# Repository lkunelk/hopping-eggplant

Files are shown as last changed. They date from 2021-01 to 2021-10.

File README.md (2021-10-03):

# pendulum
Prototype Flywheel Pendulum

## Setting up project
1. create directory catkin_ws/src/
2. clone repo into it

## Install Dependancies in package.xml
1. go to catkin_ws/ and run below command
```
rosdep install --from-paths src --ignore-src -r -y
```

## Running Simulation
1. build (need to do it first time after clone, and any time you modify c++ files)
```
cd ~/catkin_ws
catkin build
```
2. source (do it for each new terminal)
```
source build/setup.bash
```
3. launch simulation
```
roslaunch pendulum sim.launch
```

4. publish to motor directly
```
rostopic pub /flywheel_controller/command std_msgs/Float64 "data: 0.0"
```
5. graph data
```
roslaunch pendulum plots.launch
```
manually add topics to graph. You can see available topics with following:
```
rostopic list
```

7. delete and spawn new model
```
roslaunch pendulum respawn.launch
```

8. quit fast
```
./gk
```

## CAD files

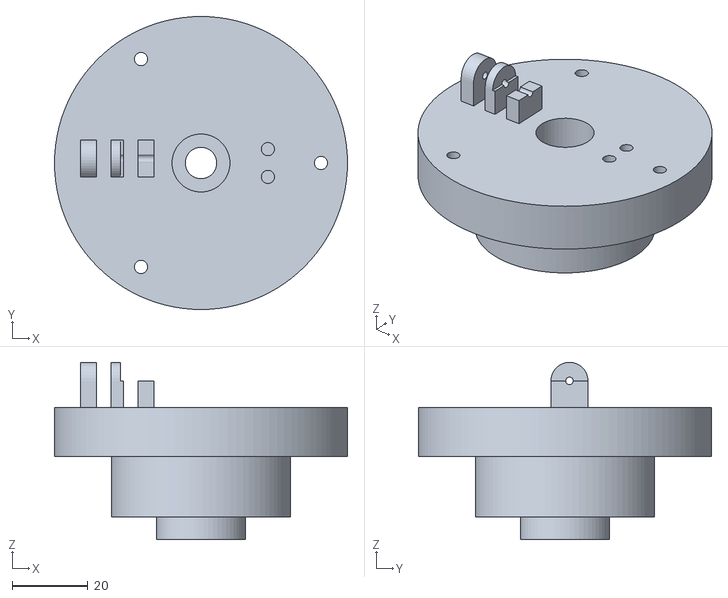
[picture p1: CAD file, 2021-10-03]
full_description/meshes/middle_v13_1.stl
77.3 x 77.3 x 46.8

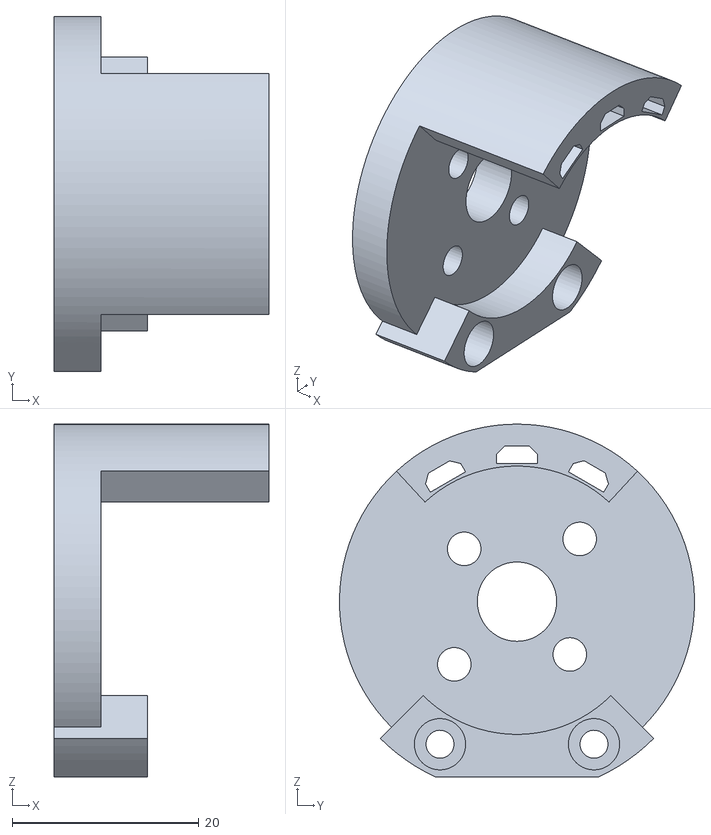
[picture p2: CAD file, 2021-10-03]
full_description/meshes/_bldc_parts.d32996c5-cb5d-48d1-b36d-40a50d399b36_v5_1.stl
23.0 x 38.0 x 37.8

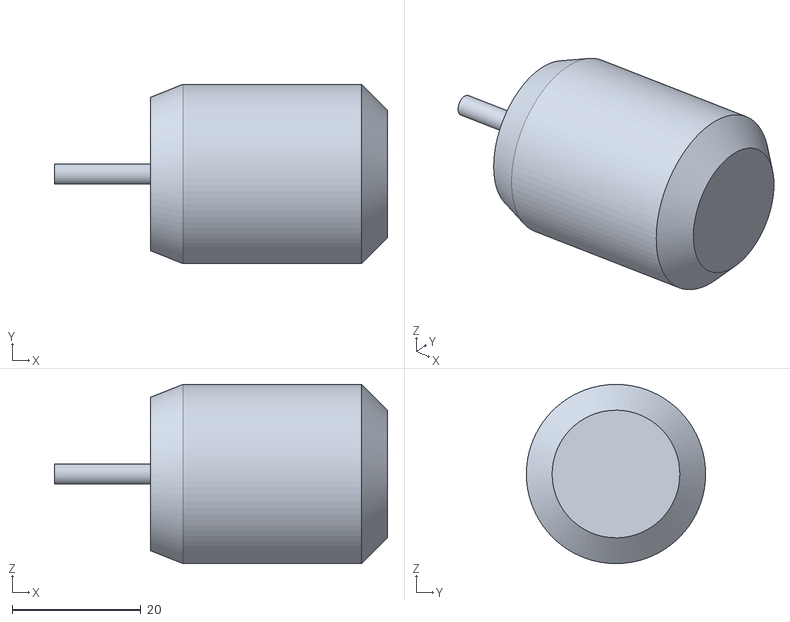
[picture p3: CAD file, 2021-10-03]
full_description/meshes/Turnigy_Aerodrive_SK3_-_2836_v2_1.stl
51.6 x 27.8 x 27.8

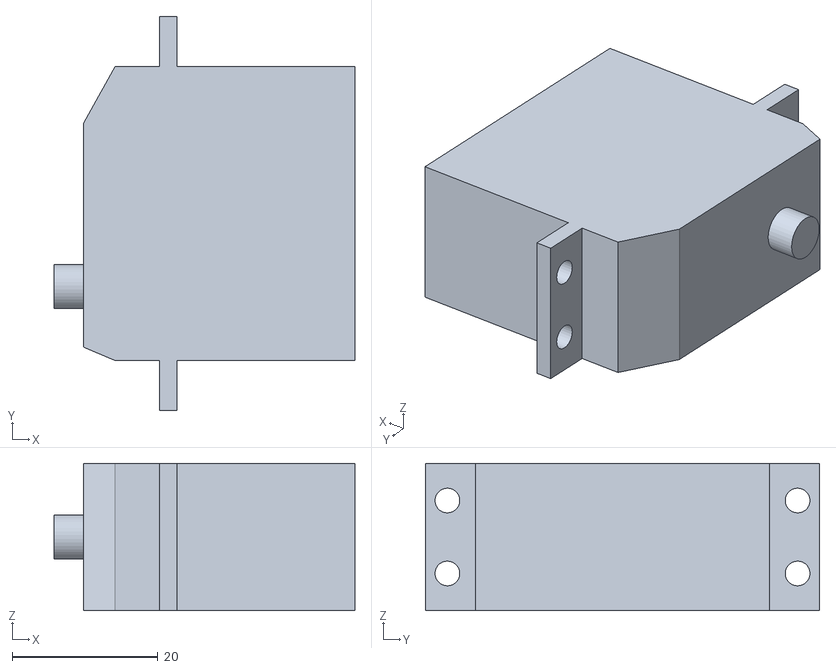
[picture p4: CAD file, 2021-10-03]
full_description/meshes/Savox_SV1270TG_v4_1.stl
41.2 x 54.0 x 20.2

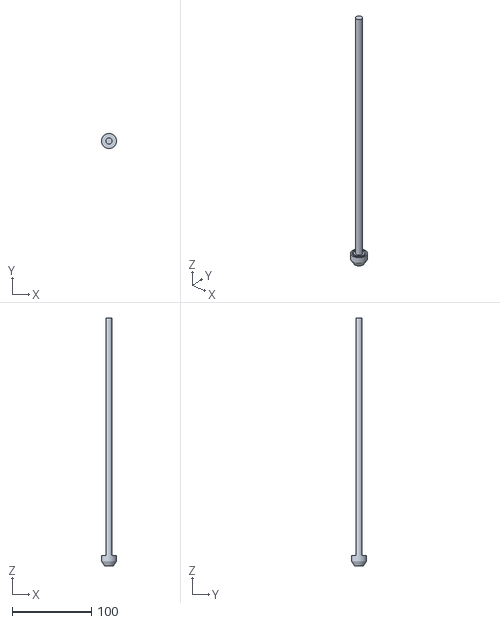
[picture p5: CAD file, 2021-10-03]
full_description/meshes/Leg_0_v2_1.stl
19.0 x 19.0 x 312.8

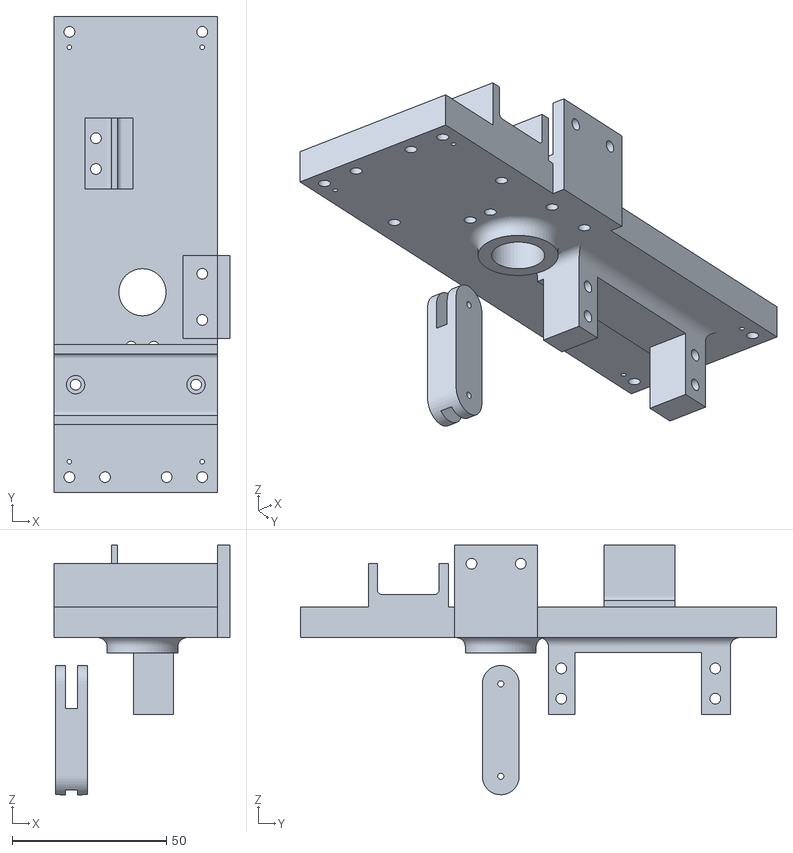
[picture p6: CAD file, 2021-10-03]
full_description/meshes/base_link.stl
57.1 x 154.5 x 81.0

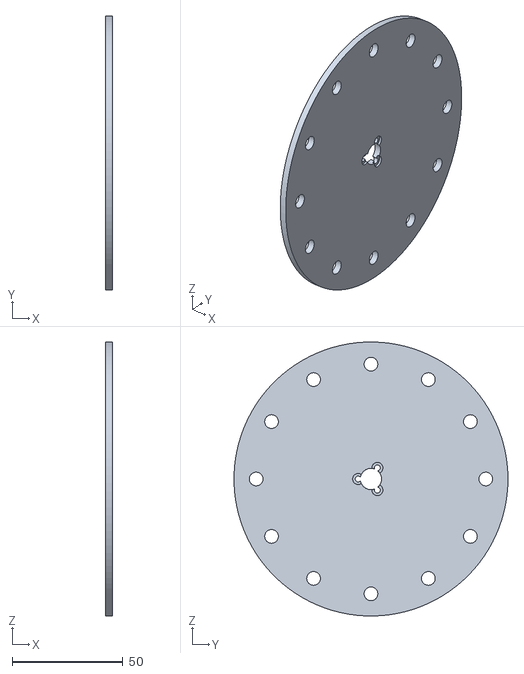
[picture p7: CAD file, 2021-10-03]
full_description/meshes/flywheel_v2_1.stl
3.00 x 123.4 x 123.4

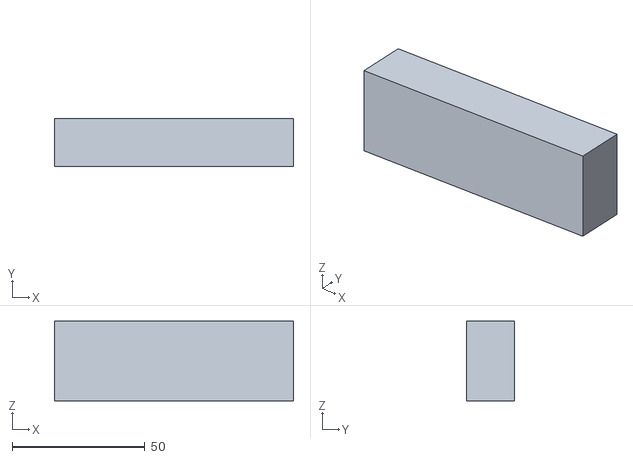
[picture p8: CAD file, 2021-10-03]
full_description/meshes/battery_v2_1.stl
90.0 x 18.0 x 30.0

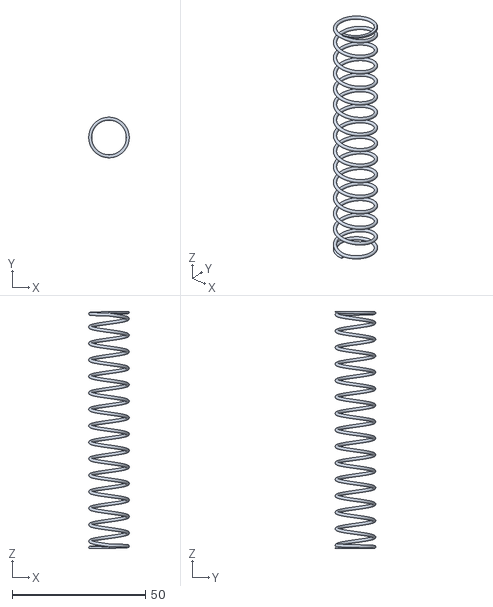
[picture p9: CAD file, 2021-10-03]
full_description/meshes/9657K449_COMPRESSION_SPRING_v1_1.stl
15.2 x 15.2 x 88.9

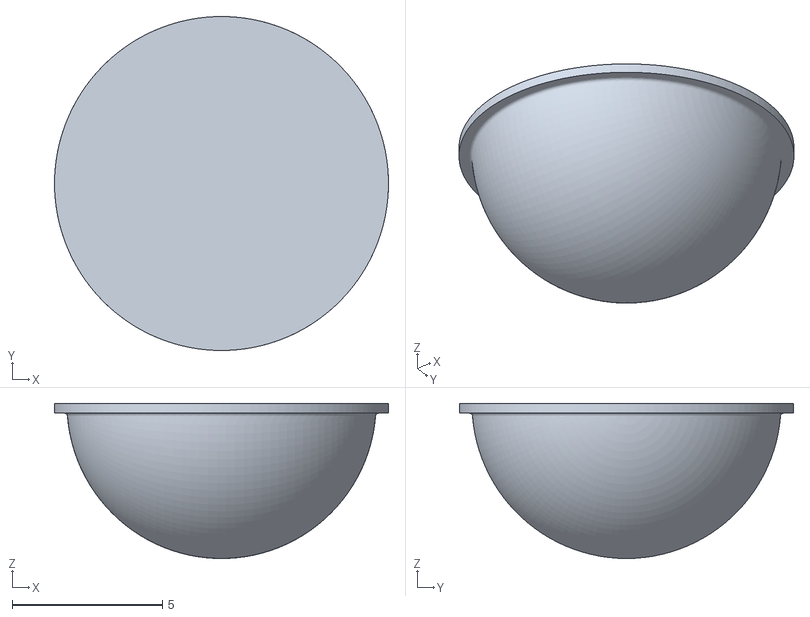
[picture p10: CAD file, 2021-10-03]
full_description/meshes/95495K673_POLYURETHANE_RUBBER_ADHESIVE-BACK_BUMPER_v1_1.stl
11.1 x 11.1 x 5.16

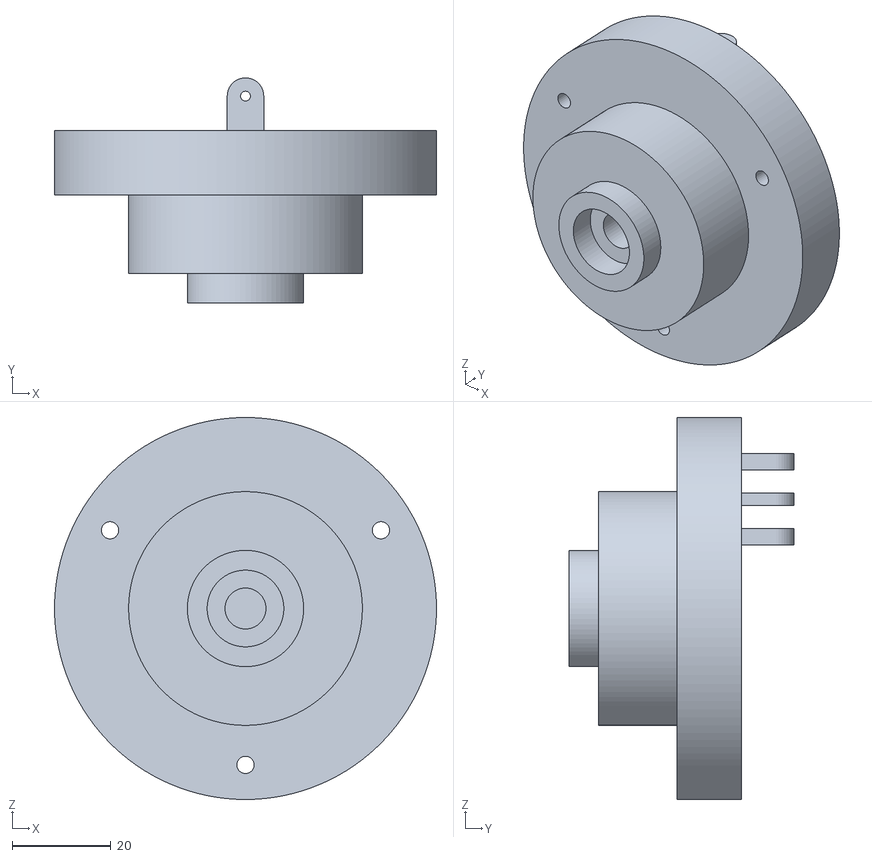
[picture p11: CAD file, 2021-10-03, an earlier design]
full_description/meshes/middle_v7_1.stl
77.3 x 45.6 x 77.3

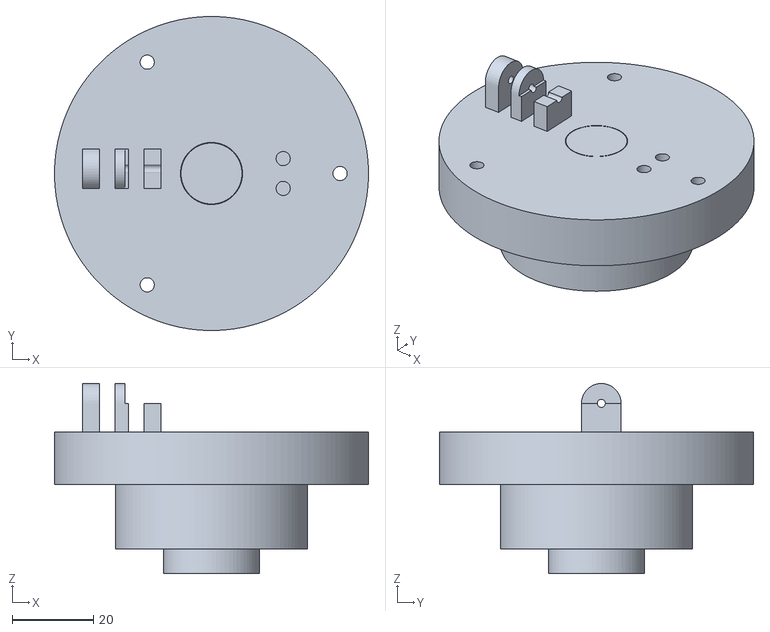
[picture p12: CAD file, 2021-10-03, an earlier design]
full_description/meshes/middle_v8_1.stl
77.3 x 77.3 x 46.8

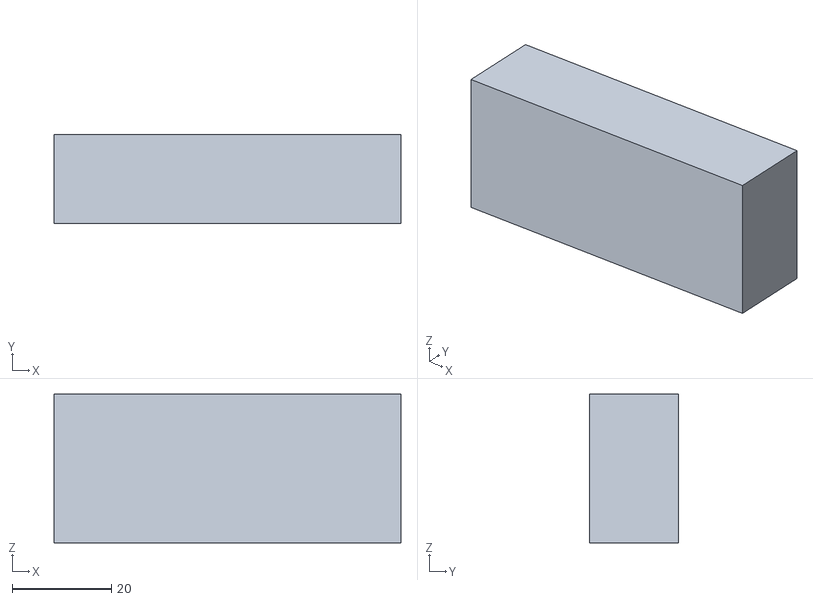
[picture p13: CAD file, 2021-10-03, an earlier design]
full_description/meshes/battery_v1_1.stl
70.0 x 18.0 x 30.0

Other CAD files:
full_description/meshes/middle_v9_1.stl

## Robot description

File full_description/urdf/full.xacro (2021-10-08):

<?xml version="1.0" ?>
<robot name="full" xmlns:xacro="http://www.ros.org/wiki/xacro">

<xacro:include filename="$(find pendulum)/urdf/imu.xacro"/>

<xacro:include filename="$(find full_description)/urdf/materials.xacro" />
<xacro:include filename="$(find full_description)/urdf/full.trans" />
<xacro:include filename="$(find full_description)/urdf/full.gazebo" />
<xacro:property name="COG_X" value="18.6E-3" />
<xacro:property name="COG_Y" value="-0.717E-3" />
<xacro:property name="COG_Z" value="202.078E-3" />

<link name="base_link">
  <inertial>
    <origin rpy="0 0 0" xyz="-0.001293985439476192 0.008696164684669999 0.19102874553521218"/>
    <mass value="0.029100376183393978"/>
    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
  </inertial>
  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
</link>

<link name="yaw_flywheel">
  <inertial>
    <origin rpy="0 0 0" xyz="0 0 0"/>
    <mass value="0.100"/>
    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
  </inertial>
  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
</link>

<link name="Savox_SV1270TG_v4_1">
  <inertial>
    <origin rpy="0 0 0" xyz="0.005831732473496099 0.02381767967516413 -0.005000421818498552"/>
    <mass value="0.05588660670883367"/>
    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
  </inertial>
  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
</link>

<link name="battery_v2_1">
  <inertial>
    <origin rpy="0 0 0" xyz="-4.21818495628494e-07 -1.7069679003611782e-15 0.014999578181500939"/>
    <mass value="0.09719999999999998"/>
    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
  </inertial>
  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
</link>

<link name="_bldc_parts.d32996c5-cb5d-48d1-b36d-40a50d399b36_v5_1">
  <inertial>
    <origin rpy="0 0 0" xyz="0.005416070476629217 -0.008249769076539576 0.017190299561071626"/>
    <mass value="0.007765972237267597"/>
    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
  </inertial>
  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
</link>

<link name="Turnigy_Aerodrive_SK3_-_2836_v2_1">
  <inertial>
    <origin rpy="0 0 0" xyz="0.018054083245234838 -1.1684663653310778e-13 -2.8213514524644268e-08"/>
    <mass value="0.07999399647342939"/>
    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
  </inertial>
  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
</link>

<link name="flywheel_v2_1">
  <inertial>
    <origin rpy="0 0 0" xyz="0.0014986943552602328 7.592667813915988e-15 -2.8213514774444448e-08"/>
    <mass value="0.100"/>
    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
  </inertial>
  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
</link>

<link name="9657K449_COMPRESSION_SPRING_v1_1">
  <inertial>
    <origin rpy="0 0 0" xyz="0.000147 -0.00055 -0.019803"/>
    <mass value="0.0"/>
    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
  </inertial>
  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
</link>

<link name="middle_v13_1">
  <inertial>
    <origin rpy="0 0 0" xyz="0.0001790821739212855 1.3992034871236863e-05 -0.07572427018815987"/>
    <mass value="0.01826712193865079"/>
    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
  </inertial>
  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
</link>

<link name="Leg_0_v2_1">
  <inertial>
    <origin rpy="0 0 0" xyz="-4.2181849628047897e-07 -9.756626929979806e-15 0.028777697727251528"/>
    <mass value="0.04388165329610352"/>
    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
  </inertial>
  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
</link>

<link name="95495K673_POLYURETHANE_RUBBER_ADHESIVE-BACK_BUMPER_v1_1">
  <inertial>
    <origin rpy="0 0 0" xyz="0.000147 -0.00055 -0.011803"/>
    <mass value="0.0"/>
    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
  </inertial>
  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
</link>

<joint name="Rigid1" type="fixed">
  <origin rpy="0 0 0" xyz="-0.003047 0.0202 0.179703"/>
  <parent link="base_link"/>
  <child link="Savox_SV1270TG_v4_1"/>
</joint>

<joint name="Rigid4" type="fixed">
  <origin rpy="0 0 0" xyz="-0.002297 -0.02945 0.203703"/>
  <parent link="base_link"/>
  <child link="battery_v2_1"/>
</joint>

<joint name="Rigid5" type="fixed">
  <origin rpy="0 0 0" xyz="0.028253 0.00705 0.213703"/>
  <parent link="base_link"/>
  <child link="_bldc_parts.d32996c5-cb5d-48d1-b36d-40a50d399b36_v5_1"/>
</joint>

<joint name="Rigid6" type="fixed">
  <origin rpy="0 0 0" xyz="0.005 -0.00825 0.015274"/>
  <parent link="_bldc_parts.d32996c5-cb5d-48d1-b36d-40a50d399b36_v5_1"/>
  <child link="Turnigy_Aerodrive_SK3_-_2836_v2_1"/>
</joint>

<joint name="yaw_flywheel_joint" type="continuous">
  <origin rpy="0 0 0" xyz="0.0 0.0 0.25"/>
  <parent link="base_link"/>
  <child link="yaw_flywheel"/>
  <axis xyz="0.0 0.0 1.0"/>
</joint>

<xacro:macro name="thruster_link" params="id">
  <link name="thruster_${id}">
    <inertial>
      <mass value="0.02" />
      <origin xyz="0 0 0" rpy="0 0 0" />
      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
    </inertial>
    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
  </link>
</xacro:macro>

<xacro:thruster_link id="0" />
<xacro:thruster_link id="1" />

<xacro:macro name="thruster_joint" params="id xyz">
  <joint name="thruster_${id}_joint" type="continuous">
    <origin rpy="0 0 0" xyz="${xyz}"/>
    <axis xyz="1 0 0" />
    <parent link="base_link" />
    <child link="thruster_${id}" />
  </joint>
</xacro:macro>

<xacro:thruster_joint xyz="${COG_X} ${COG_Y - 0.2} ${COG_Z}" id="0" />
<xacro:thruster_joint xyz="${COG_X} ${COG_Y + 0.2} ${COG_Z}" id="1" />

<joint name="flywheel_joint" type="continuous">
  <origin rpy="0 0 0" xyz="0.03675 0.0 0.0"/>
  <parent link="Turnigy_Aerodrive_SK3_-_2836_v2_1"/>
  <child link="flywheel_v2_1"/>
  <axis xyz="-1.0 0.0 0.0"/>
</joint>

<joint name="Rigid8" type="fixed">
  <origin rpy="0 0 0" xyz="0.0 0.0 -0.1148"/>
  <parent link="Leg_0_v2_1"/>
  <child link="9657K449_COMPRESSION_SPRING_v1_1"/>
</joint>

<joint name="servo_joint" type="prismatic">
  <origin rpy="0 0 0" xyz="-0.000147 0.00055 0.199703"/>
  <parent link="base_link"/>
  <child link="middle_v13_1"/>
  <axis xyz="-0.0 0.0 -1.0"/>
  <limit effort="100" lower="-0.0" upper="0.03" velocity="100"/>
</joint>

<joint name="spring_joint" type="prismatic">
  <origin rpy="0 0 0" xyz="0.0 0.0 -0.0651"/>
  <parent link="middle_v13_1"/>
  <child link="Leg_0_v2_1"/>
  <axis xyz="-0.0 0.0 -1.0"/>
  <limit effort="100" lower="-1.0" upper="1.0" velocity="100"/>
</joint>

<joint name="Rigid12" type="fixed">
  <origin rpy="0 0 0" xyz="0.0 0.0 -0.1228"/>
  <parent link="Leg_0_v2_1"/>
  <child link="95495K673_POLYURETHANE_RUBBER_ADHESIVE-BACK_BUMPER_v1_1"/>
</joint>

</robot>

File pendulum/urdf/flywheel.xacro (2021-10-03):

<?xml version="1.0"?>
<robot xmlns:xacro="http://www.ros.org/wiki/xacro" name="pendulum">
    <xacro:include filename="$(find pendulum)/urdf/imu.xacro"/>
    <xacro:property name="piston_offset" value="0.04"/> <!-- m -->
    <xacro:macro name="flywheel" params="radius length mass motor_mass arm_length solenoid_mass"> <!-- offset -->
        <link name="flywheel_link">
            <visual>
                <geometry>
                    <cylinder length="${length}" radius="${radius}"/>
                </geometry>
            </visual>
            <inertial>
                <mass value="${mass + motor_mass + solenoid_mass}"/>
                <inertia ixx="${1/12*mass*(3*radius**2 + length**2)}" ixy="0.0" ixz="0.0" iyy="${1/12*mass*(3*radius**2 + length**2)}" iyz="0.0" izz="${1/2*mass*(radius**2)}"/>
            </inertial>
        </link>

        <gazebo reference="arm2_link">
            <!-- must come before the link definition (major ???) -->
            <material>Gazebo/Blue</material>
        </gazebo>
        <link name="arm2_link">
            <visual>
                <origin rpy="0 0 0" xyz="0.01 0 0.0127"/>
                <geometry>
                    <cylinder length="0.0254" radius="0.00254"/>
                </geometry>
            </visual>
            <inertial>
                <origin rpy="0 0 0" xyz="0 0 0"/>
                <mass value="0.001"/>
                <inertia ixx="0.000001" ixy="0.00" ixz="0.00" iyy="0.000001" iyz="0.00" izz="0.000001"/>
            </inertial>
        </link>

        <gazebo reference="arm3_link">
            <!-- must come before the link definition (major ???) -->
            <material>Gazebo/Blue</material>
        </gazebo>
        <link name="arm3_link">
            <visual>
                <origin rpy="0 ${3.1415/2} 0" xyz="0.01 ${-piston_offset} 0.0"/>
                <geometry>
                    <cylinder length="0.002" radius="${piston_offset}"/>
                </geometry>
            </visual>
            <inertial>
                <origin rpy="0 0 0" xyz="0 -0.01 0.0"/>
                <mass value="0.001"/>
                <inertia ixx="0.000001" ixy="0.00" ixz="0.00" iyy="0.000001" iyz="0.00" izz="0.000001"/>
            </inertial>
        </link>

        <link name="arm4_link">
            <inertial>
                <origin rpy="0 0 0" xyz="0 0 0"/>
                <mass value="0.001"/>
                <inertia ixx="0.000001" ixy="0.00" ixz="0.00" iyy="0.000001" iyz="0.00" izz="0.000001"/>
            </inertial>
        </link>


        <xacro:imu origin="arm4_link"/>


        <joint name="arm_piston_base" type="continuous">
            <axis xyz="1 0 0"/>
            <parent link="arm_link"/>
            <child link="arm2_link"/>
            <origin rpy="0 0 0" xyz="0 0 ${arm_length}"/>
        </joint>
        <joint name="arm_piston_top" type="continuous">
            <axis xyz="1 0 0"/>
            <parent link="arm2_link"/>
            <child link="arm3_link"/>
            <origin rpy="0 0 0" xyz="0 0 0.0254"/>
        </joint>
        <joint name="servo_joint" type="revolute">
            <axis xyz="1 0 0"/>
            <parent link="arm3_link"/>
            <child link="arm4_link"/>
            <origin rpy="0 0 0" xyz="0 ${-piston_offset} 0"/>
            <limit lower="0" upper="${3.1415/4}" effort="1000" velocity="1000"/>
        </joint>

        <gazebo>
            <joint name="arm_piston_align" type="prismatic">
                <axis>
                    <xyz>0 0 1</xyz>
                    <limit>
                        <lower>-1</lower>
                        <upper>1</upper>
                    </limit>
                </axis>
                <parent>arm_link</parent>
                <child>arm4_link</child>
                <pose>0 0 0 0 0 0</pose>
            </joint>
        </gazebo>

        <joint name="flywheel_joint" type="continuous">
            <axis xyz="0 0 1"/>
            <parent link="arm4_link"/>
            <child link="flywheel_link"/>
            <origin rpy="0 ${3.1415/2} 0" xyz="0 ${piston_offset} ${radius}"/> <!-- ${offset} -->
        </joint>

        <transmission name="$arm_piston_transmission">
            <type>transmission_interface/SimpleTransmission</type>
            <actuator name="$arm_piston_motor">
                <mechanicalReduction>1</mechanicalReduction>
            </actuator>
            <joint name="servo_joint">
                <hardwareInterface>hardware_interface/EffortJointInterface</hardwareInterface>
            </joint>
        </transmission>

        <transmission name="$flywheel_transmission">
            <type>transmission_interface/SimpleTransmission</type>
            <actuator name="$flywheel_motor">
                <mechanicalReduction>1</mechanicalReduction>
            </actuator>
            <joint name="flywheel_joint">
                <hardwareInterface>hardware_interface/EffortJointInterface</hardwareInterface>
            </joint>
        </transmission>
    </xacro:macro>
</robot>

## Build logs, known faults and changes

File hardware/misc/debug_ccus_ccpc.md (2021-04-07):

Trying to get the damn COM event to trigger the loading of the OCRx and CCx[N]E registers into the shadow registers

The STM32G4xx manual suggests under its Hall sensor interfacing documentation to use the COM event along with some control bits in CR2 (CCUS and CCPC) to preload the values for the control registers in one frame of the hall ticks and have them loaded in in the next, all at the same time, synchronous with the Hall sensor itself. I wanted to start ticking on the hall sensor inputs via XOR which was separately motivated by wanting higher-resolution velocity data via its input-compare functionality, and pushing the motor tick onto that handler seemed like a good idea. I was struggling initially with getting the COM event itself to fire; the manual suggested putting the ticking code in the CCR2 handler anyways. However, I started to encounter some weird behavior.

The most persistent and actually the first problem I ran into at all was that the motor would tick veeery briefly at the edge of each hall sensor, before going quiet. This was very bizzare, it was triggering the COM interrupt even. The first major suspect was the CCR2 output to TRGO on TIM4, the "interfacing timer" that had the XOR on it. It was in PWM mode 2, which meant that it went low for the split second that CNT was below CCR2, then high for the rest of the timer period, _then low again when the one-shot expired and CNT was forced back to 0_. I knew that it had to be a posedge... but something in me suspected that maybe it was firing for the duration of that timer period (which at the time was 32MHz/32/65536 = 65ms, so pretty short), so I tried:

1. Increasing the timer prescaler. The blip didn't get longer unfortunately.
2. Changing the PWM timer mode. The wording in the manual said that TIM4 needed to send a "pulse" along TRGO, so I thought that maybe because the pulse from TIM4 as it was, spanning the whole period of the timer (65ms) was longer than the period of TIM1 (32MHz/8/256 = 64us), and maybe the update event was preloading zeroes back onto the CCR. Note that the combination of shadow registers and the trigger events were very annoyingly both invisible to debugging. Also note that the diagrams for the counter loading/capturing in the manual only show the update event as enabled by the preload enable and output mode in CCMR (see page 1112). Nothing about COM + CCUS + CCPC.

  I misread the 0b0001 option for OC2M as being a pulse only on the clock cycle where CNT == CCR2, when in fact it latched the output high. That meant I was only getting the single update at the beginning from the first hall sensor which added to my confusion. But then the moment of lucidity. I noticed that while this latching was happening, only one of the phases seemed to be energizing, and _it depended on the motor phase_. When I made all three CCRx non-zero, then it was constantly energized. When I realized my mistake with the PWM compare mode (after banging my head on why it was only energizing when I had added CCRx declarations before starting the TIM4 base) it all came together. **The enable bits were being set synchronously.** That's why the blip width was independent of the timer prescaler: it was the length between the CCR2 interrupt on TIM4 sending the TRGO to TIM1 and the motor_tick interrupt callback reaching the point where it set the compare enables.
  
Some other miscellaneous behaviors that made my night more fun:

1. Triggering the events don't actually do some things: e.g. triggering the CCR2 event on TIM4 didn't send the TRGO; triggering TRIG on TIM4 also doesn't do the trigger behavior for the one-shot counter. IT just sets the interrupt flags and triggers interrupt handlers and DMA. It's not exactly like generating those events.
2. Thanks to the latching of the 0b0001 option, I thought that the COM interrupt only fired when the registers changed. This kind of comparison with the existing value was also related with the fact that only one coil was energized: possibly it was forcing an equality with the initial set value of the register. Of course that was all wrong.
3. The COM interrupt doesn't work if both CCUS and CCPC aren't set together. I wanted to avoid them and still get the interrupt to verify the trigger was firing and hopefully also get the coils energized more permanently. Kind of makes sense, kind of a pain though. (Possibly weaker than that, for sure the interrupt doesn't fire if CCPC isn't set. This isn't noted in the manual).

Still... it's weird. I haven't actually 100% verified this yet in the original setup. I'm weirded out by the fact that I didn't catch this despite stopping in the `motor_tick` handler before the enables were set, since it's the last thing. I'm pretty sure it was still blipping despite the CCER being consistent...

Ah. It does work. My guess is that initially I was confused by the triggering: I thought that the event triggering would be enough to get the first pulse in, so when it didn't work I didn't investigate further. Clearly now I see that it fires properly before getting clobbered by the CCR set.

Now. The question. Is WHY?! Is this a mistake in the documentation? Clearly it says that CCxE and CCxNE are buffered alongside CCR... 

Ohhh shiittttttt it was the OPPOSITE! CCR is being set synchronously, while CCx[N]E is set on the next cycle. Sigh... But then why was my motor spinning? Ah. I had offset it by the other amount. So... that should've been it? Man. How did I misread that? I thought OCxM was the compare register thanks to Arduino's training me of OCxRA/B... DAMMIT. It all makes sense. When I was pausing after setting all the registers to 0, it was really all zeroes. And it was out of phase with the CCxE/NE. God.

I guess this makes sense, for any sinusoidal business/doing other analog things inside the the hall sensor period, we want to keep the CCR registers synchronous. Just... dammit man.

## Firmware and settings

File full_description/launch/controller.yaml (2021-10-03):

full_controller:
  # Publish all joint states -----------------------------------
  joint_state_controller:
    type: joint_state_controller/JointStateController
    publish_rate: 50

  # Position Controllers --------------------------------------
  flywheel_joint_position_controller:
    type: effort_controllers/JointPositionController
    joint: flywheel_joint
    pid: {p: 100.0, i: 0.01, d: 10.0}
  servo_joint_position_controller:
    type: effort_controllers/JointPositionController
    joint: servo_joint
    pid: {p: 100.0, i: 0.01, d: 10.0}
  spring_joint_position_controller:
    type: effort_controllers/JointPositionController
    joint: spring_joint
    pid: {p: 100.0, i: 0.01, d: 10.0}

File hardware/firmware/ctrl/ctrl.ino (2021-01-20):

#include <Servo.h>
#include <util/atomic.h>

Servo S;
// deadband: 494-530 (482us-517us)
#define AMIN 104
#define AMASK 0xFFF8
#define ASTRIDE 8
#define LG_ASTRIDE 3
#define ANUM 55

// conversion
#define DCOEFFSNUM 5
#define DCOEFFSDELAY 0
const float DCOEFFS[DCOEFFSNUM] = { 0.250f,-1.333f,3.000f,-4.000f,2.083f }; // { 0.167f,-1.200f,3.750f,-6.667f,7.500f,-6.000f,2.450f };

#define HANNINGNUM 9
#define HANNINGDELAY 4
const float HANNING[HANNINGNUM] = { 0.000f,0.037f,0.125f,0.213f,0.250f,0.213f,0.125f,0.037f,0.000f };

float ALOOKUP[ANUM] = {
  3.04687500e-01f,  2.90039062e-01f,  2.68798828e-01f,  2.39990234e-01f,
  2.16796875e-01f,  1.92382812e-01f,  1.62841797e-01f,  1.40869141e-01f,
  1.19628906e-01f,  9.83886719e-02f,  7.39746094e-02f,  5.68847656e-02f,
  4.68750000e-02f,  3.19824219e-02f,  2.34375000e-02f,  1.70898438e-02f,
  9.27734375e-03f,  3.17382812e-03f, -2.44140625e-04f, -3.17382812e-03f,
  -6.59179688e-03f, -1.07421875e-02f, -1.46484375e-02f, -1.83105469e-02f,
  -2.19726562e-02f, -2.58789062e-02f, -3.07617188e-02f, -3.66210938e-02f,
  -4.24804688e-02f, -4.63867188e-02f, -5.00488281e-02f, -5.41992188e-02f,
  -5.81054688e-02f, -6.17675781e-02f, -6.54296875e-02f, -7.00683594e-02f,
  -7.54394531e-02f, -8.03222656e-02f, -8.39843750e-02f, -8.76464844e-02f,
  -9.25292969e-02f, -9.83886719e-02f, -1.03515625e-01f, -1.07666016e-01f,
  -1.11328125e-01f, -1.15966797e-01f, -1.21826172e-01f, -1.26953125e-01f,
  -1.30859375e-01f, -1.35498047e-01f, -1.41113281e-01f, -1.46728516e-01f,
  -1.52343750e-01f, -1.57714844e-01f, -1.62841797e-01f
};

#define LOOP_FREQ 32 // Hz
#define LOOP_PERIOD 31250 // us
uint16_t aint = 0;

#define ABUFNUM 32
#define ABUFMASK 31
volatile int16_t abuf[ABUFNUM] = { 0 };
volatile uint8_t abuf_idx = 0xFF;
int16_t abuf_stash[ABUFNUM] = { 0 };
uint8_t abuf_idx_stash = 0, last_abuf_idx_stash = 0; // hope it doesn't lap itself
float abuf_rad[ABUFNUM] = { 0 };

#define DEADBAND_PLUS 20
#define DEADBAND_MINUS 0

// controller output is flywheel acceleration  in units of m/s^2
#define PID_I 1003.1f // 0.07071068f
#define PID_P 39000.0f // 14736.6f // 14736.6f // 1.03875926f
#define PID_D 4600.0f // 20356.0f // 20356.0f // 1.43485934f

#define UMID 1500
#define UMIN 1140
#define UMAX 1860
#define BAND_MINUS 360 // DERIVED: UMID - DEADBAND_MINUS - UMIN
#define BAND_PLUS 340 // DERIVED: UMAX - DEADBAND_PLUS - UMID
#define USAFE 1900
volatile uint16_t u = 1500; // ESC input
float vfly = 146.73f; // flywheel speed in rad/s
float ci = 0.0f;
#define A0 (3.864E3f) // units of flywheel acceleration in rad/s^2
#define VMAX (1.394E3f) // units of rad/s (assume flywheel dominates)
#define VSAFE (600.0f)
#define IFLY (70.49E-6f) // units of kg-m
// timing + -> flywheel CCW accel -> arm CW torque
// arm CCW -> analog - -> angle +

uint8_t stopped_ = 0, initted_ = 0;

// TODO it's probably a lot faster to do this in units of ms directly
#define T_ADC 0.001024f
#define A0_T_ADC 506.464 // 126.616f // DERIVED: T_ADC * A0 * VFLY_UPDATE_T
#define VFLY_UPDATE_T 128
//#define LG_VFLY_UPDATE_T 5
volatile uint8_t vfly_update_ticks = 0;
ISR(ADC_vect) {
  abuf[(++abuf_idx) & ABUFMASK] = ADC + 8;
  // (((uint16_t)ADCH) << 8) | ADCL; // <- surprisingly this didn't work
  // ^ maybe those aren't volatile, or the cast made it non-volatile
  // casting as volatile uint16_t didn't work either
//  digitalWrite(13, abuf_idx & 1);
  ADCSRA |= 1 << 4;

  // update vfly estimate (for lack of a better place to do this)
  digitalWrite(13, ((vfly_update_ticks) & (VFLY_UPDATE_T - 1)) == 0);
  if(initted_ && ((++vfly_update_ticks) & (VFLY_UPDATE_T - 1)) == 0) {
    if(u > UMID) {
      vfly += ((u - (UMID + DEADBAND_PLUS)) / (float)BAND_PLUS - (vfly / VMAX)) * A0_T_ADC;
    }
    else {
      vfly -= ((UMID - DEADBAND_MINUS - u) * A0_T_ADC) / BAND_MINUS;
      vfly = fmax(0.0f, vfly);
    }
  }
}

volatile uint8_t cnt = 0;
ISR(TIMER2_COMPA_vect) {
  ADCSRA |= 1 << 6; // start ADC conversion
  // 115bpm -> 1.916Hz - 2^5 upscale -> 61.3Hz - 1024x upscale - 256x upscale -> 16MHz (yes)
}

void setup() {
  // put your setup code here, to run once:
  S.attach(2);
  Serial.begin(9600);
  pinMode(13, OUTPUT);

  // disable interrupts while setting up the conversions and spinning the wheel up
  cli();
  
  // configure ADC
  ADMUX |= (0b01 << 6) | 0b0011; // A3 input
  ADCSRA |= (0b11 << 6) | (1 << 3 | 0b110); // 64 prescaler (conversion takes 104us)

  // note: MUST USE TIMER2. Arduino millis uses timer0, servo uses timer1.
  // also can't auto-trigger: ADC doesn't accept triggers from timer2. Of course not.
  TCCR2A |= 0b11; // CTC OCR2A top
  TCCR2B |= (1 << 3) | 0b111; // 1024 prescaling
  OCR2A = 15; // subdivide further by ~16x~ 4x, get ~1ms~ 256us sampling period
  TIMSK2 |= 0b010;
  
  sei(); // begin collecting data

  pinMode(10, INPUT_PULLUP);
//  pinMode(11, OUTPUT);
//  analogWrite(11, 40);
  S.writeMicroseconds(1560); // initialize at middle velocity
//  delay(5000);
//  
//  delay(10);
}

// estimating velocity based on a model of torque (from current) and saturation velocity
// (which is non-linear with velocity possibly due to resistive torque that is proportional to velocity)
// 1520 -> 0Hz, 1607ms -> 122Hz, 1740ms -> 183Hz, saturates just above this
uint8_t debouncer[32] = { 0 };
uint8_t debouncer_idx = 0;
uint8_t ticks = 0;
void loop() {
//  return; 
//  uint16_t b = map(a_raw, 0, 1023, 1200, 1900);
//  S.writeMicroseconds(b);
//  Serial.println(b);
//  digitalWrite(13, HIGH);
//  delay(10);
//  return;
  // estimate pid
  debouncer[(++debouncer_idx) & 31] = !digitalRead(10);
  uint8_t s = 0;
  for(uint8_t i = 0; i < 32; i++) {
    s += debouncer[i];
  }
  
  if(s > 30 && !stopped_) {
    ATOMIC_BLOCK(ATOMIC_RESTORESTATE) {
      memcpy(abuf_stash, abuf, sizeof(abuf[0]) * ABUFNUM);
      abuf_idx_stash = abuf_idx;
    }
    
    // I, analog -> rad conversion
    {
      float cibuf = 0.0f;
      uint8_t i = initted_ ? (last_abuf_idx_stash + ABUFNUM - 1) : 0;
      uint8_t j = 0;
      uint8_t imax = initted_ ? abuf_idx_stash : ABUFMASK;
      for(; (i & ABUFMASK) != (imax & ABUFMASK); i++, j++) {
        uint16_t a_raw = constrain((int16_t)abuf_stash[(i + 1) & ABUFMASK] - AMIN, 0, ASTRIDE * (ANUM - 2));
        
        uint16_t aidx = a_raw >> LG_ASTRIDE;
        int8_t ares = a_raw - (aidx << LG_ASTRIDE);
        float a = ALOOKUP[aidx];
        abuf_rad[(i + 1) & ABUFMASK] = ((ares * (ALOOKUP[aidx + 1] - ALOOKUP[aidx])) / ASTRIDE) + ALOOKUP[aidx];
        cibuf += a;
      }
      if(j > 0) {
        cibuf /= j;
        ci += cibuf;
      }
      last_abuf_idx_stash = abuf_idx_stash;
    }
    
    // D, P
    float cdbuf[DCOEFFSNUM] = { 0 };
    // INVARIANT: ABUFNUM > HANNINGNUM + DCOEFFSNUM
    for(uint16_t i0 = (uint16_t)abuf_idx_stash + ABUFNUM - HANNINGNUM - DCOEFFSNUM, j0 = 0; j0 < DCOEFFSNUM; i0++, j0++) {
      for(uint16_t i = i0, j = 0; j < HANNINGNUM; i++, j++) {
        cdbuf[j0] += abuf_rad[i & ABUFMASK] * HANNING[j];
      }
    }
    
    float cp = cdbuf[DCOEFFSNUM - 1]; // DCOEFFSDELAY - 
    
    float cd = 0;
    for(uint8_t i = 0; i < DCOEFFSNUM; i++) {
      cd += cdbuf[i] * DCOEFFS[i];
    }
    cd /= T_ADC;
    
    float A = PID_P * cp + PID_D * cd + PID_I * ci;
  
    if(A > 0) {
      if(vfly > VSAFE) {
        stopped_ = 1;
        return;
      }
      u = UMID + DEADBAND_PLUS + (vfly / VMAX + A * 1.4f / A0) * BAND_PLUS;
      u = min(USAFE, u);
    }
    else {
      // braking
      // simple ratio
      float b = -fmax(A * 6.0f, -A0) / A0;
      u = UMID - DEADBAND_MINUS  - sqrt(b) * BAND_MINUS;
      u = max(UMIN, u);
    }
    S.writeMicroseconds(u);

    Serial.print(A, 4); Serial.print('\t'); Serial.print(u); Serial.print('\t'); Serial.println(abuf_rad[abuf_idx_stash & ABUFMASK], 4); /* Serial.print('\t'); Serial.print(ci, 4); Serial.print('\t');
    Serial.print(vfly, 4); Serial.print('\t'); Serial.print(u); Serial.print('\t'); Serial.println(A, 4); */
    
    initted_ = 1;
  }
  else if(initted_) {
    // reset state
    ci = vfly = u = 0;
    stopped_ = 1;
    S.writeMicroseconds(UMIN);
  }
  else {
    if((ticks++) & 31 == 0) {
      S.writeMicroseconds(1560);
    }
    delayMicroseconds(1500);
  }

//  delay(50);
  
  // // estimate vfly
  
  
  // abuf[(abuf_idx++) & ABUFMASK] = a;
  // u[0] += (P * a) >> PPOINT;
  // u[0] = constrain(u[0], UMIN, UMAX);
  // S.writeMicroseconds(UMID + (u[0] * (u[0] > 0 ? 1 : 10) + (u[0] > 0 ? DEADBAND_PLUS : -DEADBAND_MINUS))); // step over deadband
  // Serial.print(a);
  // Serial.print('\t');
  // Serial.println(u[0]);
  // delayMicroseconds(LOOP_PERIOD);
//  digitalWrite(13, HIGH);
}

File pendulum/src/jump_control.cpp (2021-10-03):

#include <algorithm>
#include <boost/circular_buffer.hpp>

#include "consts.hpp"
#include "gazebo_msgs/LinkStates.h"
#include "ros/ros.h"
#include "sensor_msgs/JointState.h"
#include "std_msgs/Bool.h"
#include "std_msgs/Float64.h"
#include "util.hpp"

const float MAX_ANGV = 9.04f * 0.04;  // rad/s, 0.1s/60deg
const float T_STALL = 2.8f / 0.04;    // N-m

bool lastTouchSensorVal = false;
bool fireServo = false;
ros::Time beginFireServo;

ros::Publisher commandPub;
std_msgs::Float64 commandMsg;

void base_contact_cb(const std_msgs::Bool msg) { lastTouchSensorVal = msg.data; }

// emulate simplified servo motor dynamics
void servo_emulation_cb(const sensor_msgs::JointState &msg) {
  int joint_idx = idxOf(msg.name, PRISM_JOINT_NAME);
  float v = msg.velocity[joint_idx];

  if (fireServo) {
    commandMsg.data = T_STALL * (1.0f - fmax(0.0f, fmin(1.0f, v / MAX_ANGV)));
  } else {
    commandMsg.data = -40.0;  // retract servo
  }

  commandPub.publish(commandMsg);
}

void controlUpdate() {
  // if we touched ground fire servo for set amount of time
  if (fireServo) {
    ros::Duration dur = ros::Time::now() - beginFireServo;
    bool timeExpired = dur.toSec() > 0.1;
    if (timeExpired) {
      fireServo = false;
    }
  } else if (false) {  // lastTouchSensorVal == true) {
    ROS_INFO("Fire Servo!");
    fireServo = true;
    beginFireServo = ros::Time::now();
  }
}

int main(int argc, char **argv) {
  ros::init(argc, argv, "prism_ctrl");
  ros::NodeHandle n;

  commandPub = n.advertise<std_msgs::Float64>("arm_controller/command", 1000);

  ros::Subscriber sub = n.subscribe("joint_states", 1000, servo_emulation_cb);
  ros::Subscriber sub_base_contact = n.subscribe("base_contact", 1000, base_contact_cb);

  ros::Rate rate(1000);  // Control update rate (Hz)
  while (ros::ok()) {
    controlUpdate();
    ros::spinOnce();  // process all the callbacks
    rate.sleep();
  }

  return 0;
}

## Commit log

2021-01-10 got the geometry of the setup
    [arm.xacro, flywheel.xacro, model.sdf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]
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2021-01-17 Initial commits from Derek's side
    [pot_align.csv]
2021-01-17 Clean up repo root
    [pot_align.csv]
2021-01-17 fix pendulum to the world
    [pendulum.xacro]
2021-01-20 Update control
    - Control sim program now simulates pure delay (thought this was a cause
    for problems on the hardware).
    - Add latching toggle switch for balance tests on the hardware to start
    and stop the control loop
    - Tune control gains on the hardware ad-hoc. Things that are making it better:
    - More aggressive P
    - Less aggressive D (too much noise, even with smoothing)
    - Way higher gain overall (1.4x in the forward direction, 6x in the braking
    direction)
    - Concave-down braking dynamics: not sure it this is correct but it seems
    the Quicrun 10BL60 ESC is not linear in braking torque, potentially speed-
    dependent too
    [ctrl.ino]
2021-01-22 implement PI controller - pendulum goes upright!
    [flywheel.xacro, pendulum.xacro]
2021-01-25 add arm angle limit, control limits for torque and speed based on motor parameter
    [arm.xacro, pendulum.xacro]
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2021-01-25 add motor to base_arm joint
    [arm.xacro]
2021-02-02 Added control for prismatic joint
    [arm.xacro, pendulum.xacro]
2021-02-02 Debug prismatic joint + default offset
    Prismatic joint is now working with a PID controller (command emitted
    by main controller which is a bit weird but works for now). Also, the
    sim now starts with an initial rotation using the command-line option
    in the gazebo.launch file. Both are in service of simulating the foot
    fall of the robot.
    [arm.xacro]
2021-02-02 Make a pendulum that swings on impact
    Strangely, the choice of joints in the robot seems to impact what
    the landing behavior is very strongly. In a separate stash (to be
    committed), the robot bounces on impact, whereas here we get the
    expected behavior of the arm swinging due to the momentum of the
    motor and wheel.
    This situation is much more challenging for the controller, which
    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
    [arm.xacro, flywheel.xacro, pendulum.xacro]
2021-02-03 Throw it on the grouuund
    Add an initial velocity so the controller doesn't have time to correct
    the initial angle too much, so we know what the behavior is like when
    it impacts at an angle. Also tweak the urdf params for more realistic
    physics.
    [arm.xacro, pendulum.xacro]
2021-02-04 Reorient in midair to land along footfall axis
    Calculate the landing angle and change the position setpoint to it.
    Also debounce the contact messages. Just like real life!
    Code is a little ad-hoc and messy, sorry! Needs to be cleaned up a bit.
    [pendulum.xacro]
2021-02-07 Make custom node for prismatic joint controller
    Implement a custom controller for the prismatic joint, implementing the spring
    within as well. This controller for now applies a constant force whenever the
    joint is expanding to increase jump height over time.
    Note the joint controller rate needed to be updated because the existing 50Hz
    was too slow for the spring physics to converge. I don't know if we really
    _need_ 1kHz but it does (seem to) work at that rate at least.
    Also refactor the contact detection to its own separate node now that two
    controllers are using it.
    [arm.xacro, pendulum.xacro]
2021-02-07 Remove prismatic publisher in main
    Accidental hangover from the built-in PID testing on the prismatic controller,
    this was causing the spring to fail previously. Now it makes more sense
    (although lower hz still behave differently than higher hz)
2021-02-07 Implement hopping with a pull solenoid
    Pull on the solenoid as the robot lifts off the ground to compress a
    spring, let go when the robot is at the bottom of its bounce. Surprisingly
    the energy transfer is not very efficient and the bounce seems to get lost
    in the default frictions of the system. To my understanding this is already
    among the best timings for a pull solenoid.
    A push solenoid transfers more energy by foregoing the energy storage spring
    altogether, and of course you can make one by just flipping one of the links
    around. Let's try that next.
    [arm.xacro]
2021-02-08 Use solenoid on push stroke, move to top of pendulum
    Using a separate spring to store the solenoid energy is inefficient,
    because the solenoid force is non-linear with length, so any spring
    would either be too stiff near equilibrium, or too soft at max
    compression. This is detailed in the previous commit too. Now, the
    solenoid uses a push stroke (to be achieved physically by flipping
    one of the interfaces to the links upside down and using a pull stroke)
    and is able to deliver more energy.
    Also, @lkunelk 's suggestion fixed the energy loss issue from the
    inelastic collisions at the solenoid and spring end stops by putting
    all the mass on one end, so the systems before and after the collisio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
    [arm.xacro, flywheel.xacro]
2021-02-09 Begin tracking a 1D path
    Reorient while lifting off to track a position given by a tracker object
    in the world. Involved some refactors because link and joint
    orders
    started changing based on which model was read in first.
    [arm.xacro, flywheel.xacro, pendulum.xacro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]
2021-02-09 Make all principal inertias non-zero
    Turns out Gazebo just really doesn't like it when the inertias are
    zero. I wanted them that way so the dummy links I'm putting in to,
    say, join a revolute and prismatic joint together don't affect the
    simulation results. However, turns out setting them to zero does
    the exact opposite and ruins the entire sim. In the first case a
    few commits ago, the zero inertia on the base link was preventing
    the whole robot from rotating when it hit the ground, which
    happened to be fixed by adding a fixed joint to a dummy link
    before the prismatic spring joint. I had thought it was a problem
    with the revolute+prismatic combo somehow, but it recurred here
    when adding the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
    [flywheel.xacro, pendulum.xacro]
2021-02-09 Add global constraints to robot
    Force the robot into the YZ plane to reduce the instabilities of landing
    on a corner of the base link. Does this defeat the purpose of using
    a 3D simulator? Temporarily, yes. These are training wheels, since the
    energy of the solenoid is just enough to overcome the losses baked into
    the system. Note that these joints also seem to take energy out of the
    system, so the simulation as a whole needs some evaluation from an
    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
    [flywheel.xacro, pendulum.xacro]
2021-02-11 Better estimate landing angle, re-enable path tracking
    Previously, we were using the position of the base link to estimate the
    trajectory of the robot, but as the robot repositioned to land, the
    link would swivel and threw off the estimate. The ideal solution is to
    track the center of mass, and now that almost all the mass is at the
    top of the robot, we can just track the flywheel. However, the flywheel
    isn't the part that's hitting the ground, so we have to compensate.
    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
    [arm.xacro, pendulum.xacro]
2021-02-11 Begin custom worldfile and physics
    Set CFM and update rate at launch time for Gazebo. Previously, the
    robot was sliding (and violating momentum conservation) because the
    contact was unstable due to the many prismatic things happening in the
    arm. With softer constraints, the friction is more accurate at the
    default physics update step. Hopefully this doesn't take too much
    energy out of the system.
    Other changes:
    - Default physics rate set to 50 (prev. 1000)
    - Camera changed to look at the robot head-on from the front (+Y)
2021-02-22 Hotfix the friction on the base link
    Asking for @lkunelk 's help debugging the friction in Gazebo. It refuses
    to read both the in-<link> and <gazebo> friction definitions for me, +
    the CFM definition for the link.
    [pendulum.xacro]
2021-02-22 Succesfully set friction on arm link
    moved the friction tag so it's specified after the
    arm is specified
    [arm.xacro, pendulum.xacro]
2021-02-22 Remove name from base link collision
    Friction (and kp) was being stripped from base_link during parsing because
    of a bug in gazebo's URDF->SDF conversion. See osrf/gazebo#2497 . Fixing the
    base link friction should eliminate the need for CFM/KP which was initially
    put in to improve the collision detection with the world and stop the
    robot from slipping during the pushoff phase.
    [pendulum.xacro]
2021-02-23 Analyze and tune solenoid
    These changes are part of experiments to understand the sensitivities
    of the solenoid. They revealed for the DSTL-0829 solenoid we're using
    that the initial force plateau means that the energy transfer is
    entirely through the speed of the body's mass, because the spring
    won't compress under this force profile. This is alarming, as the
    only useful part of the solenoid force is whatever it manages to
    generate at maximum extension. Unfortunately, precompressing the
    solenoid actually doesn't lead to significant gains even with the
    optimal spring (e.g. one whose K follows the slope of the solenoid
    force curve).
    It's worth now exploring other options for the hopping join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
    [flywheel.xacro, pendulum.xacro]
2021-02-23 Try to make a servo piston using position joint
    ODE doesn't like D=1.4. Go figure. Will try to do this softer with a
    custom effort-based controller.
    Also, oops, forgot all this time to include `util.cpp`
    [arm.xacro, flywheel.xacro]
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2021-02-26 Shrink simulation step in the config
    Needed to make the simulation resolve the servo torque limiting: it now
    doesn't slam the spring into the limit, but behaves according to a
    differential equation; the spring doesn't actually end up
    compressing further because it's massless (see
    `servo_piston_linear_analysis.ipynb` in the current `main` branch)
    [flywheel.xacro]
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2021-03-02 Use CLion's automatic code refactoring
    Refactoring function will help to make code consistent.
    Currently just using the default code style with indent=2
    [arm.xacro, flywheel.xacro, pendulum.xacro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]
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2021-03-04 flip the order of joints to match real world robot
    [arm.xacro]
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2021-04-02 clean up urdf files
    [arm.xacro, flywheel.xacro, pendulum.xacro]
2021-04-03 remove free joint at the leg
    [arm.xacro]
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2021-04-04 play around with parameters
    [imu.xacro]
2021-04-04 add plotjuggler dependacy + launch plots with sim
    [imu.xacro]
2021-04-05 Track ESC driver code
    Hall sensors are finally working properly, so finally shove this code into
    the repo.
    [g431_test Debug.cfg]
2021-04-06 Use XOR on hall sensors instead of timer loop
    The config for the timer interaction between TIM1 and TIM4 needed a bit
    of futzing beyong what CUBE provided to get both the hall edge-to-edge delay
    and the COM preloading/interrupt behavior, which can be seen in the user code
    section in main.
    - TIM4 capture 1 and output compare 2 need to be enabled (fair enough)
    - TIM4 commutation delay (i.e. CCR2) needs to be >0 to trigger COM
    (unexpected: the default CUBE delay is 0): this is because otherwise
    the reset trigger won't generate a posedge for TIM1 to catch
    - TIM1 CR2 needs to enable both CCUS and CCPC to trigger COM on the
    tim_trgi input (coming from TIM4's CCR2)
    - TIM1 DIER needs to expli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
    [g431_test.ioc, main.c, motor.c]
2021-04-07 Fix CCUS and CCPC commutation
    I thought that both CCxR and CCxE were preloaded via COM, but it turns out
    just CCxE is. This commit gets the motor spinning and the data collecting.
    Read the debug note for all the fun details.
    [g431_test.ioc, main.c, motor.c]
2021-04-11 First attempt at control
    Rudimentary PID and filtering in the motor loop. Currently, control updates
    are in the hall-sensor callback, but this doesn't make sense, given the control
    loop speed is then tied to motor speed. The open-loop timer callback on TIM6 has
    been revived to deal with standstill - this is where the control loop will
    probably end up living.
    [g431_test.ioc, main.c, motor.c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]
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2021-06-05 Add MPU6050 calibration
    See https://github.com/jrowberg/i2cdevlib/issues/585 for more details
    on the calibration and ongoing problems with it. The short story is
    that the Z axis low byte remains uncalibrated.
    [MPU6050_DMP6_test.ino]
2021-06-05 Calculate motor parameters and tune PID/drive, fix low-speed motor behavior
    Commit title undersells it a bit, lots of changes here.
    - Run open-loop tests at various duty cycles to find the motor parameters
    (dynamic fricion F0, speed consant Kv, torque constant (per unit volt) Ki,
    drag B)
    - Fix the control optimization/LQR code (control-sim.ipynb) and use these
    motor parameter values to calculate a new controller
    - Admire how close these values were to the manual tuning we had before
    (where we were previously about 5x more aggressive)
    - Add speed reduction to the controller via feedback on the current speed
    - Convert all the parameters into the units used in the microcontroll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
    [g431_test.ioc, main.c, motor.c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]
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2021-06-14 Fix energization, start using UART
    Energization repair during direction change wasn't quite right before so
    it is fixed here. Also, we're starting to use UART to communicate the
    sensor values from the sensor manager (Arduino) to this controller. This
    allows us to get several fields of data (gyro and tilt components, etc.).
    [g431_test.ioc, main.c, motor.c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]
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2021-06-16 separate ros stuff into its own folder
    [arm.xacro, flywheel.xacro, g431_test Debug.cfg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]
2021-06-16 add autogenerated fusion model
    [95495K673_POLYURETHANE_RUBBER_ADHESIVE-BACK_BUMPER_v1_1.stl, 9657K449_COMPRESSION_SPRING_v1_1.stl, Leg_0_v1_1.stl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]
2021-06-28 give spring wide limits, piston eyeball the limits
    [full.xacro]
2021-06-28 add spherical collision remove all other collisions
    [full.xacro]
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2021-09-29 Balancing milestone with AMT-103 encoder
    The robot now balances itself and rejects some disturbances.
    1. AMT103 was brought up, and immediately showed much smoother motor
    performance over the previous ad hoc hall sensor design:
    - Designed a sinusoidal commutation sequence to replace the 6-step
    algorithm from before. The timer CCRs form 3-phase sinusoids relative
    to 50% duty, with both OCx and OCxN active.
    - Experiments were done about the latter point, but having both OCx and
    OCxN active seems to improve stability and power transfer. Without a
    scope trace I speculate that the inductance is high enough and the PWM
    pulse short enough that providing a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
    [MPU6050.cpp, MPU6050_DMP6_test.ino, g431_test.ioc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]
2021-09-29 Track motor characterization scripts and latest AMT-103 perf data
    The motor characterization script in `turnigy_char` has been updated for
    the data collected from UART during the AMt103 bringup. Also several new
    analysis scripts for the motor part selection and control simulations.
    The existing control simulation in particular has been updated to reflect
    the changed accelerometer and gyro units (see previous commit).
    [130.csv, 220.csv, 220_110_3s.csv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]
2021-10-03 Create preliminary yaw flywheel controller
    Find the [robot frame] yaw offset such that its world frame X has no world frame
    Z component. This lets the main flywheel correct offsets vs. gravity.
    **NOTE** For now, the yaw controller is *also* controlling the main flywheel
    because it has solved the linear relevant angles that are necessary for the
    flywheel control.
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2021-10-08 Add thrusters
    Import `uuv_simulator`'s thruster plugins and start using them for force
    generation. Fix inertias that were exported by Fusion2URDF as 0, which is
    not handled well by ODE (seems to handle them like ~1kg*m^2)
    [full.xacro]
